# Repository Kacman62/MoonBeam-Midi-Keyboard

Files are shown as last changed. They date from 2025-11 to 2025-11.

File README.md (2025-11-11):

# MoonBeam Synthesizer
A standalone DAWLESS synthesizer based on a Raspberry Pi Pico. Includes a custom circuit board and codebase with the Mozzi Audio Library

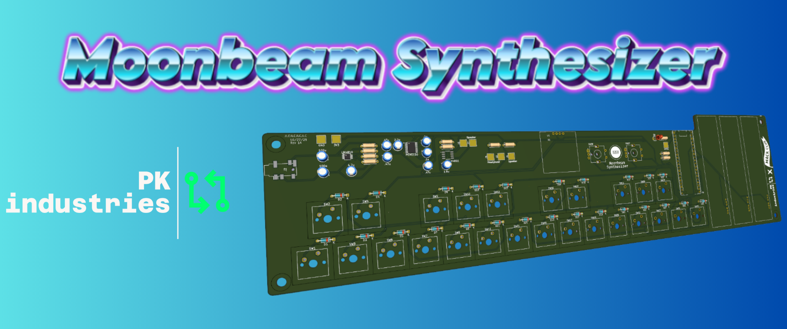
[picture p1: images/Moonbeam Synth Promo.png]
Promo Image for the Moonbeam Synth


# Features

- 25 multiplexed piano style keys
- Support for up to 5 notes at the same time
- 3 Analog sliders for volume pitch and vibrato
- OLED display and 2 rotary encoders with a custom code base
- Sound synthesis using the Mozzi audio library
- 4 different wave forms
- Custom ADSR editing
- Oscilloscope style waveform viewer
- Toggleable speaker and headphone out
- And more planned features for the future!

# Initial Idea
After reading the guide from Hack club and others online to make a MIDI keyboard, it seemed like a great idea. After more research though I wanted a standalone synthesizer that does not need a computer and couldn't find many examples online. This seemed like it would be easy enough so I decided to do it myself

# Schematic and Board
The whole project is built around a raspberry pi pico 1 (a pico 2 should work too but untested). A 5x5 multiplexed array of key cap switches serve as the main input. 
On the Audio side, a PCM5100 I2S DAC is channeled into a LM4810 and LM4861 audio amplifiers, that go to a speaker and headphone jack.

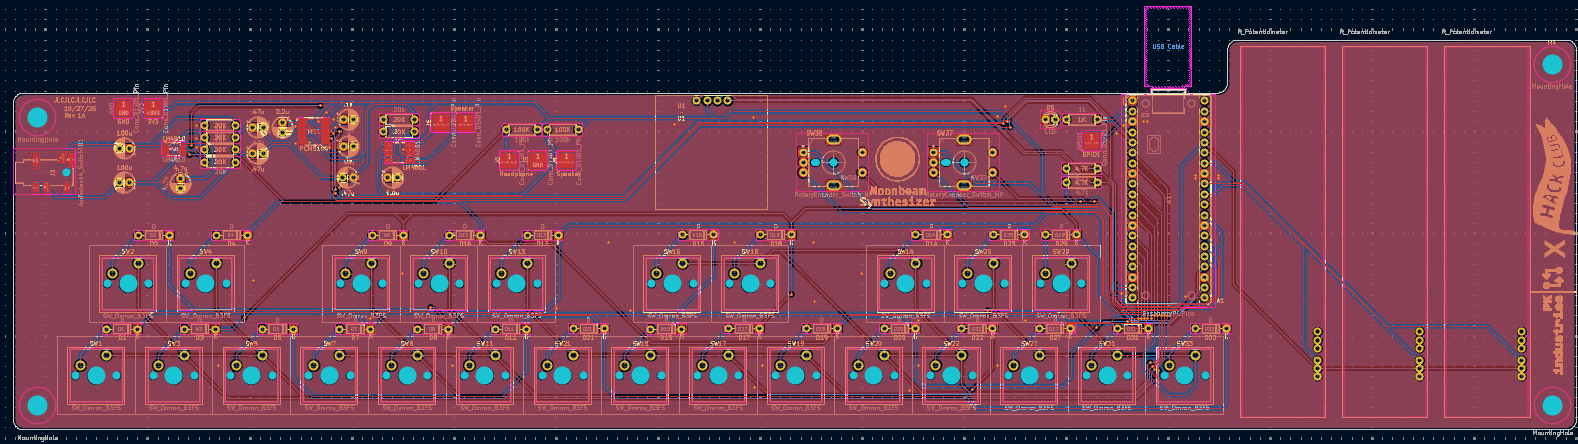
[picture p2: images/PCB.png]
Image showing routing of PCB


The PCB was a lot more challenging, just due to the sheer size of it. It ends up being about 350mm x 90mm. But the routing wasn't too hard and I like the look of how it turned out

# Case Design
There is an included case. Currently I have not received the board so I can not confirm if it works perfectly, but I designed it around the 3D cad of the board so it should work fine. 
Only 1 of each file needs to be printed and it is assembled using M4 hardware

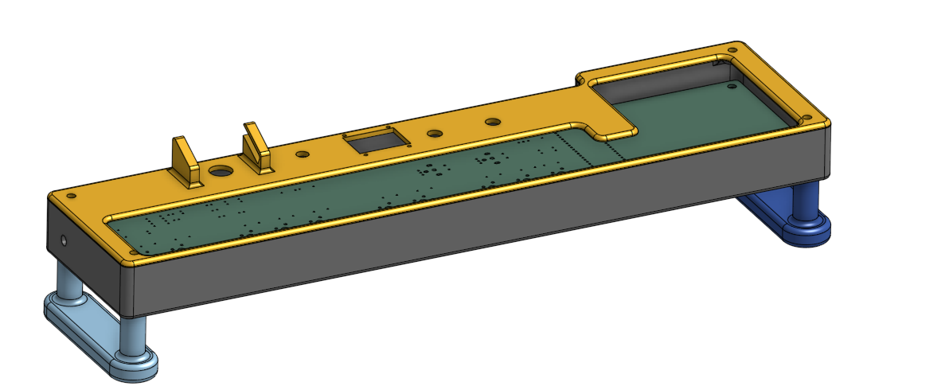
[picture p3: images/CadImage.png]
Image showing CAD of the case


# Software
I initially dreaded the software but it ended up being very fun after the initial hurdles. The code is split into 2 cores, 1 for audio and 1 for the digital UI. It should work with the final assembly, all the digital has been tested, but the audio is using I2S which I can't test currently. I did use it a little bit with PWM audio and that worked fine. The waveform viewer also does show an audio signal so Im pretty confident that it will work

# UI
You navigate the UI with both rotary encoders. Double clicking either brings you into the main menu. Rotate either to select an app.
* Settings (Wrench): View current notes on each audio voice and the values of the slide potentiometers
* ADSR Editor (Envelope): Use one dial to change the level of the ADSR and the other to change the time. Changing the level of the decay, sustain and release will change the other two with it. this is intended to avoid weird audio clipping
* Wave Viewer (Wave): View the current outputted wave form. Automatically adjusts the zoom if multiple voices are playing
* Wave Changer (Square Wave): Choose from either a sin, triangle, saw, or square wave

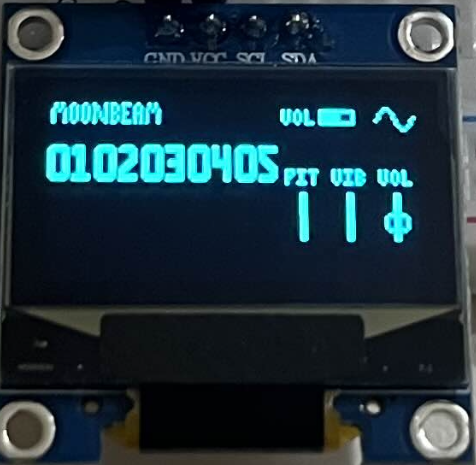
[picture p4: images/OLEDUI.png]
Image showing the settings UI


# Art
All pixel art was created by me using Aseprite. The PK Industries and the Moonbeam synth logo are unregistered trademarks, not real companies and products, and have no legal binding on anything. I am not a lawyer, and this joke has gone on too long.

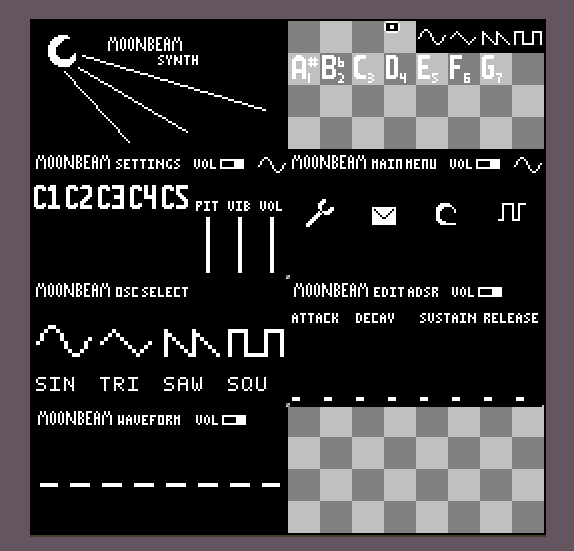
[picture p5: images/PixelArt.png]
Image showing the pixel art for the project


# Disclaimers
If you want to know more about the design and build process check out the journal

This project is sponsored by and made in collaboration with Hack Club, go check them out

Consider this project untested. I have put my full effort into this project and fully believe that it will work, but I have not received boards yet and thus do not know if this will work first try

# Hack Club Stuff

Estimate Total Hours: 48

My Final Total: 60.31

Your Final Total: 96.73

https://blueprint.hackclub.com/projects/928 

# Update 11/11

Huge thanks to Hack Club and the Blueprint program for assisting in this project. I have now received funding for the project and will be ordering parts. Expect future updates at the start of December

# Known issues
In settings, the note played is incorrect (going to wait for boards to arrive so I can assign keys different notes)

In Wave changer, the picture of the sawtooth wave is reversed from what is seen in the wave viewer

In Wave Viewer, the wave slides around randomly. (The wave is still representative of what the audio out looks like, it's just hard to focus on it)

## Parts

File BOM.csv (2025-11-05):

Product Name | Comapny | Product Link | Product Cost | Product Amount | Cost | Running Total | Do I have it? | My Total
Moonbeam Synth PCB | JLCPCB | https://github.com/Kacman62/MoonBeam-Midi-Keyboard/tree/main/PCBFiles | 32.9 | 1 | 32.9 | 32.9 | No | 32.9 | Includes Shipping
Pi Pico 1 | Vilros (really anywhere) | https://vilros.com/products/raspberry-pi-pico?src=raspberrypi | 4 | 1 | 4 | 36.9 | Yes | 32.9 | Pico 2 should work
Slider Potentiometers | Aliexpress | https://www.aliexpress.us/item/3256809748308736.html?curPageLogUid=286Us6b7kMqx | 1 | 3 | 3 | 39.9 | Yes | 32.9
Rotary Encoders | Aliexpress | https://www.aliexpress.us/item/3256808587124048.html?curPageLogUid=wcP5dpBKu0Kg | 5.72 | 1 | 5.72 | 45.62 | Yes | 32.9 | Comes in pack of 5, need 2
.96in OLED | Amazon | https://www.amazon.com/AITRIP-Display-Self-Luminous-Compatible-Raspberry/dp/B0F6SGQ9LZ | 11.99 | 1 | 11.99 | 57.61 | Yes | 32.9 | Comes in pack of 5, need 1. Careful that pinout is same, these are notorious for being unstandard
Keyswitches | Aliepress | https://www.aliexpress.us/item/3256808022543969.html?curPageLogUid=UsRw9gs5AusE | 6.05 | 1 | 6.05 | 63.66 | No | 38.95 | Buy 30 pack
Key Caps | Aliexpress | https://www.aliexpress.us/item/3256805328092200.html?gatewayAdapt=glo2usa4itemAdapt | 1.99 | 1 | 1.99 | 65.65 | No | 40.94 | Buy 30 pack
Speaker | Amazon | https://www.amazon.com/uxcell-Magnetic-Round-Shape-Replacement-Loudspeaker/dp/B08264X3KM | 5.49 | 1 | 5.49 | 71.14 | Yes | 40.94 | Pack of 2, need 1
Switch | Amazon | https://www.aliexpress.us/item/3256808627501124.html?curPageLogUid=D0IPUzBiYYWY | 2.84 | 1 | 2.84 | 73.98 | Yes | 40.94 | Pack of 5 need 1
Headphone Jack | LCSC | https://www.lcsc.com/product-detail/C128987.html?s_z=n_headphone | 0.19 | 5 | 0.95 | 74.93 | Yes | 40.94 | Min order 5, need 1
Various capacitors |  |  |  |  | 0 | 74.93 | Yes | 40.94 | might be slightly cheaper on lcsc, but just get a variety pack
Various Resistors |  |  |  |  | 0 | 74.93 | Yes | 40.94 | might be slightly cheaper on lcsc, but just get a variety pack
20k Resistors | LCSC | https://www.lcsc.com/product-detail/C119609.html?s_z=n_20k%2520resistor%2520tht | 0.046 | 10 | 0.46 | 75.39 | No | 41.4 | I need 20k resistors
THT LED |  |  |  |  | 0 | 75.39 | Yes | 41.4 | Optional for debugging
Diodes | LCSC | https://www.lcsc.com/product-detail/C402212.html?s_z=n_1n4148%2520diode | 0.009 | 50 | 0.45 | 75.84 | No | 41.85
PCM5100 I2S DAC | LCSC | https://www.lcsc.com/product-detail/C544856.html?s_z=n_pcm5100 | 1.06 | 1 | 1.06 | 76.9 | No | 42.91
LM4861 Speaker Amp | LCSC | https://www.lcsc.com/product-detail/C383073.html?s_z=n_lm4861 | 0.169 | 5 | 0.845 | 77.745 | No | 43.755 | Make sure to get an amp thats good for your speaker if you have one already. most are pin compatible
LM4810 Headphone Amp | LCSC | https://www.lcsc.com/product-detail/C2871753.html?s_z=n_lm4810 | 0.59 | 1 | 0.59 | 78.335 | No | 44.345
Various M4 Hardware
LCSC Shipping estimate and fees |  |  |  |  | 11.31
Aliexpress Shipping |  |  |  |  | 1.99 |  |  |  | If you buy more than i did you might get free shipping
With Taxes |  |  |  |  | 47.01
 |  |  |  |  |  | 96.73 |  | 60.31 | FINAL TOTAL

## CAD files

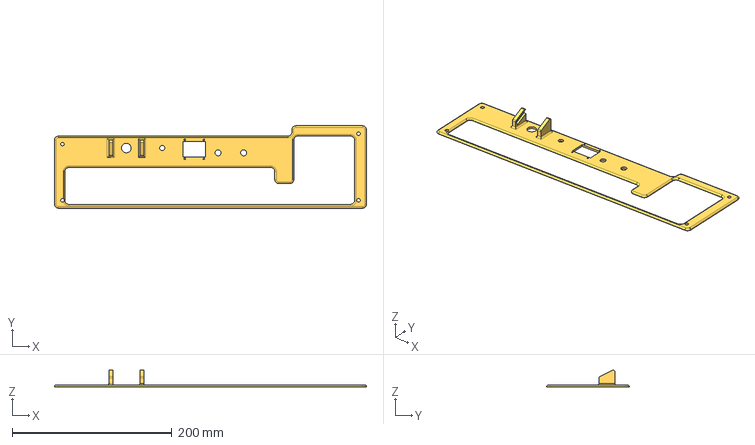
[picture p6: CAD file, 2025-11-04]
CadFolder/MoonBeam Midi Keyboard parts Copy 1 - Lid(3).step
391.0 x 103.5 x 21.3 mm

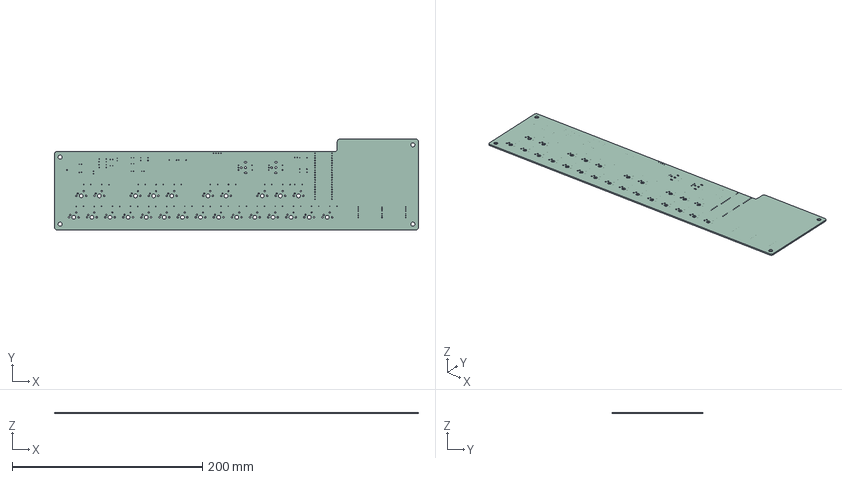
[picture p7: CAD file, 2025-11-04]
PCBFiles/Moonbeam Midi Keyboard parts Copy 1 - MoonBeam Midi Keyboard_PCB.step
383.0 x 95.5 x 1.51 mm

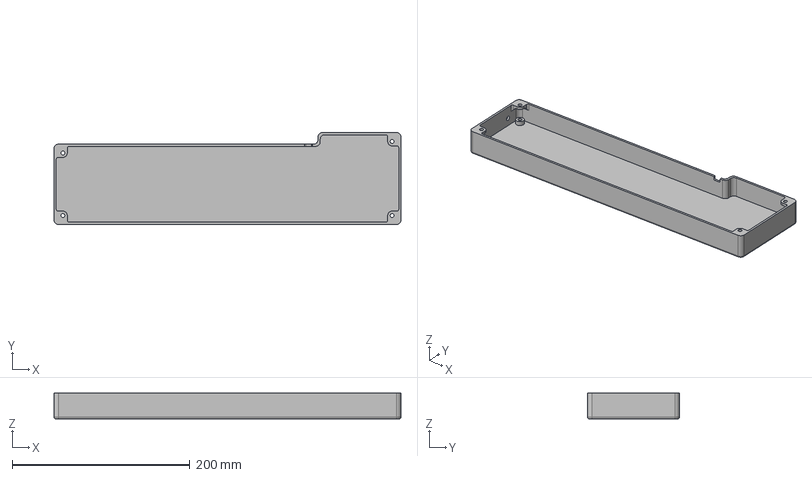
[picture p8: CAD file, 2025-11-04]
CadFolder/MoonBeam Midi Keyboard parts Copy 1 - Case.step
391.0 x 103.5 x 29.0 mm

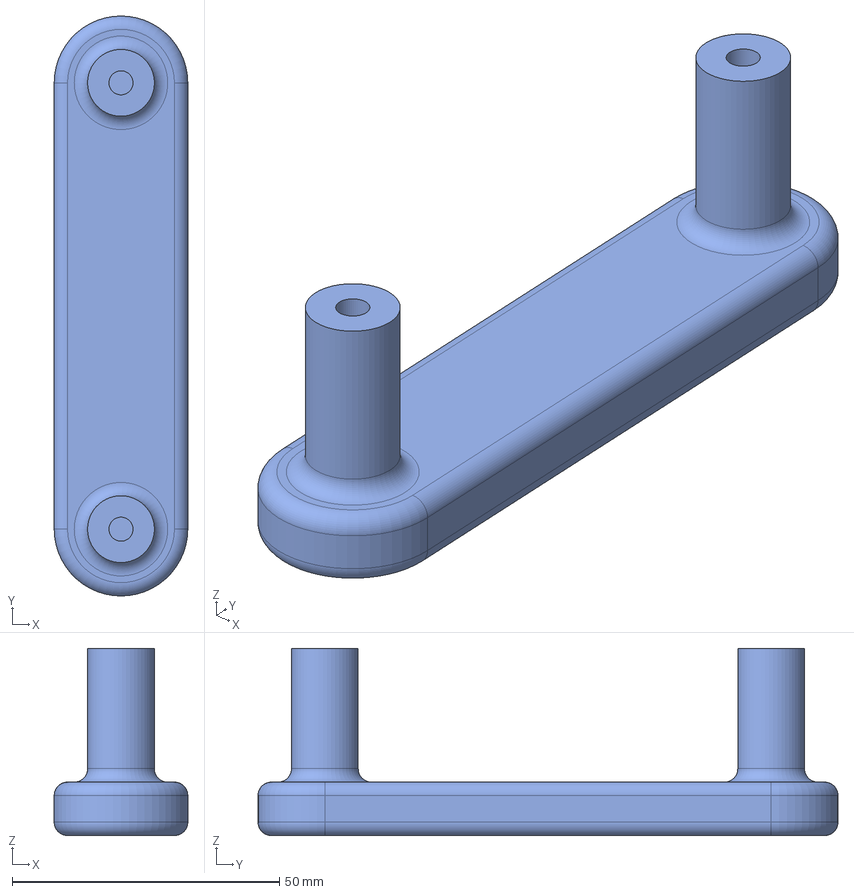
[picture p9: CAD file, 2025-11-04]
CadFolder/MoonBeam Midi Keyboard parts Copy 1 - Long Feet.step
25.0 x 108.5 x 35.0 mm

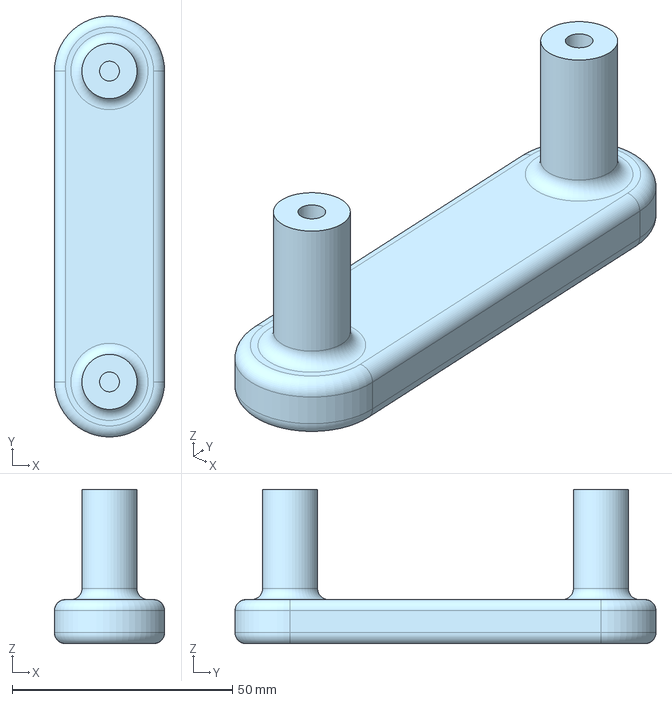
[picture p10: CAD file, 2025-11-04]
CadFolder/MoonBeam Midi Keyboard parts Copy 1 - Short Feet.step
25.0 x 95.5 x 35.0 mm

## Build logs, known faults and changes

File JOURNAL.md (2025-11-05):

<!--
  ===================    !!READ THIS NOTICE!!   ====================
  DO NOT edit this file manually. Your changes WILL BE OVERWRITTEN!
  This journal is auto generated and updated by Hack Club Blueprint.
  To edit this file, please edit your journal entries on Blueprint.
  ==================================================================
-->

## 10/25/2025 - First Prototype  



I spent most of this time in research. I liked the guide put out by hack club, but wanted a fully digital synthesizer, not just the controller. After looking at different chips and MCUs, I found that the mozzi library with a pi pico and an analog multiplexer and DAC would probably get me the best results. Before going into major PCB design, I wanted to make a breadboard cut down version just to prove it. I did get audio out of the speaker, and the next step is to get inputs and outputs from the pico.  

## 10/26/2025 1 PM - Finished Breadboard Prototype  



I spent most of this time upgrading the prototype. I added more buttons to 12, added another slide potentiometer, an I2C screen. 

I also started making code (with a lot of help from AI) it shows promise but I am having trouble getting the notes to sustain, so I might need to write the code myself.

Before that though, im going to design the PCB next and finalize the features. Going good so far though.  

## 10/26/2025 6 PM - Completed Schematic  




Spent a lot of this time researching how to get audio out. I took a headphone jack out of a broken usb adapter and wired it up in the schematic. I decided to use the pcm5100, and two TI chips, the lm4810 amd the 4861 to amplify the speaker and the headphones. Also did some other cleaning up, made a new footprint for the slide pots, added debug LEDS.

Next Im going to set out the PCB

## 10/27/2025 6 PM - Laid out and Routed PCB  





I laid out the PCB today. It was pretty challenging to get it all to fit together logically and in a small footprint. It ended up being about 350mm x 90mm. I'm pretty happy with how it looks and next I will work on making a cool silkscreen.

I also routed the PCB today, getting the multiplexed buttons was a little challenging, but I got it all done with a pretty small amount of vias. 

## 10/27/2025 9 PM - Added Silkscreen  




Went through all the components and added silkscreen of their values to make assembly easy. also added my and hack clubs logos. and found a moon pattern and added that to the back of the PCB. Also went to Logo.com and got a logo for the project made.

## 10/28/2025 - Cleaned Up Board and Started Code  



Mainly just cleaned up a bunch of loose ends this session. I cleaned up some routing things, replaced an LED with a GPIO test pad, adjusted the back silkscreen. I made a test print to see if the switch placement was good and it felt a little far away from front to back so I moved the back row closer to the front.

I also started (vibe) coding using the Mozzi audio library. the audio portion looks good, but i'm going to go back and try and make it myself.

Mainly just need to finish code and make a case before it is ready to be shipped.  

## 10/30/2025 - Started Case Design, Cleaned up Prototype Code  



Worked on the first version of the case. I like it, but it seems big so its going to be a real challenge to print and will need to be multiple pieces, so I will look into alternatives and optimizations.

Also cleaned up code for the prototype and started migrating it to the new design which uses a slightly different design than the prototype. 

I think im going to try multi core on the Pi Pico, but that will be my first time so I will see what happens.

## 11/1/2025 - Finished Case Design  



Finished the first revision of the case design. Had to go back and forth changing dimensions on the board and found that I put the wrong footprint on 1 screw hole. I think it looks pretty good but the lid doesn't seem super good so I might go back later. Looking like 200-250 grams for the entire thing which im pretty happy with.

Now its code time

## 11/2/2025 7 AM - More Coding  



Started by fixing some minor things in the CAD (forgot holes for the ports)
Then started adding in the OLED into the code. I got multicore on the pi pico, but for some reason the u8g2 graphics library didnt seem to work. (it could be multi core, or weird I2C pins, or a cheap knockoff OLED i dont really know). The adafruit ssd1306 and gfx libraries did work though. I also made a pixel art logo for the project.

Next steps are too modify parameters for the audio from the OLED.

## 11/2/2025 2 PM - Coded Main Menu  



Worked a lot on art and cleaning up code and some really weird bugs. I found out that the way i did multi core made core 0 freeze when core 1 started so i fixed that. I did more pixel art, creating graphics for what wave form is selected. Also added functions to change waveform and ADSR for later. biggest part though was creating the main menu screen where you can see the value of the sliders and in the future, what note is being played on each channel.

going really well so far i just really hope it works  

## 11/3/2025 - Added Menu Selection, Fixed Nasty Bug  



I added a rotary encoder and a menu selection screen as well as drawing icons for that. (last journal made this a little confusing this is the "main menu" that was like the main control page that shows what the synth is doing generally). I fixed a really weird bug with the encoders where the screen was drawing too many times and the delay in I2C writes was causing the encoders to not register rotations. (this issue was present across 2 different encoder libraries).

Ive got the wave form selector, the wave viewer, and the envelope editor left and then im done!  

## 11/4/2025 10 AM - Added ADSR Editing and Waveform Switching  



I added two more menus today with "art" for both. You can now switch wave forms to either sin, triangle, saw, or square. The icon in the banner also changes accordingly. 

I also added a way to change the ADSR curve of the waveform. you use one rotary encoder to change time and the other to change the level. 

Going to add 1 last app to view the current outputted wave, like an Oscope and then im going to be done with software for now.

## 11/4/2025 4 PM - Finished Code with Waveform Viewer  



I think im finished with the code. I added a waveform viewer for the audio out. It works with different wave types and (should) change with the pitch and vibrato sliders. 

This code has been a beast but im going to upload it to the github have some people review it and then ship on the weekend.

## 11/4/2025 7 PM - Shipped  

Moonbeam Synth Promo

Made a promo image for the project. Created a BOM. updated the Github a lot. uploaded code, cad, PCB files. Also shipped the project and waiting for review. 
So happy with how this turned out and cant wait to get it and continue making improvements on it.

## 11/5/2025 - Shaved $30 Off BOM  

I got over my fear of Aliexpress and got the total cost for me and you down by $30. Amazon shipping was pretty expensice. Now im ready to ship and start ordering pieces. 



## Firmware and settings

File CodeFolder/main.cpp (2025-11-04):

#include "Wire.h"
#include "pico/multicore.h"
#include "core_shared.h"

///////
#include <MozziConfigValues.h>// include this first, for named option values

#define MOZZI_AUDIO_MODE MOZZI_OUTPUT_I2S_DAC

#define MOZZI_AUDIO_CHANNELS MOZZI_STEREO           // set to stereo mode

#define MOZZI_AUDIO_BITS    16  // available values are 8, 16 (default), 24 (LEFT ALIGN in 32 bits type!!) and 32 bits
#define MOZZI_I2S_PIN_BCK                        2 // /BLCK) default is 20
#define MOZZI_I2S_PIN_WS (MOZZI_I2S_PIN_BCK+1)  // CANNOT BE CHANGED, HAS TO BE NEXT TO pBCLK, i.e. default is 21
#define MOZZI_I2S_PIN_DATA                       18 // (DOUT) default is 22
#define MOZZI_I2S_FORMAT MOZZI_I2S_FORMAT_PLAIN

#define AUDIO_RATE 16384
#define MOZZI_CONTROL_RATE 128

#include <Mozzi.h>                                  // *after* all configuration options, include the main Mozzi headers

#include <Oscil.h>
#include <ADSR.h>

#include <tables/sin2048_int8.h>
#include <tables/saw2048_int8.h>  
#include <tables/square_no_alias_2048_int8.h> 
#include <tables/triangle2048_int8.h>



#define VOL_POT   A0   // GP26
#define PITCH_POT A1   // GP27
#define VIB_POT   A2   // GP28

volatile float masterVol = 1.0f;
volatile float pitchOffset = 0.0f;
volatile float vibDepth = 0.0f;

#define NUM_COLS 5
#define NUM_ROWS 5

Oscil<SIN2048_NUM_CELLS, AUDIO_RATE> osc[NUM_VOICES] = {
  Oscil<SIN2048_NUM_CELLS, AUDIO_RATE>(SIN2048_DATA),
  Oscil<SIN2048_NUM_CELLS, AUDIO_RATE>(SIN2048_DATA),
  Oscil<SIN2048_NUM_CELLS, AUDIO_RATE>(SIN2048_DATA),
  Oscil<SIN2048_NUM_CELLS, AUDIO_RATE>(SIN2048_DATA),
  Oscil<SIN2048_NUM_CELLS, AUDIO_RATE>(SIN2048_DATA)
};

ADSR<CONTROL_RATE, AUDIO_RATE> env[NUM_VOICES];

volatile SharedADSR adsrSettings;

volatile bool ADSR_FLAG = false;
volatile bool OSC_FLAG = false;

volatile OSCState wave = SIN;

extern const unsigned char sinWave[];
extern const unsigned char triWave[];
extern const unsigned char sawWave[];
extern const unsigned char squareWave[];
extern const unsigned char* waveTable[];

Oscil<SIN2048_NUM_CELLS, AUDIO_RATE> lfo(SIN2048_DATA);  // LFO for vibrato

int voiceNoteIndex[NUM_VOICES] = {-1, -1, -1, -1, -1};

volatile float notePlayArray[NUM_VOICES] = {-1, -1, -1, -1, -1};

int voicesPlaying = 0;

int ButtonMatrixRow[NUM_ROWS] = {4, 5, 6, 7, 8};
int ButtonMatrixCol[NUM_COLS] = {9, 10, 11, 12, 13};

float noteFreqs[NUM_ROWS * NUM_COLS] = {
  261.63, 277.18, 293.66, 311.13, 329.63,
  349.23, 369.99, 392.00, 415.30, 440.00,
  466.16, 493.88, 523.25, 554.37, 587.33,
  622.25, 659.25, 698.46, 739.99, 783.99,
  830.61, 880.00, 932.33, 987.77, 1046.5
}; //C4-C6

void scanMatrix();
void triggerVoice(int);
void releaseVoice(int);
void core1_entry();
void updateADSR();
void updateOSC();

void setup(){


  //Blink LED so i know its working (ONLY FOR DEBUGGING)
  pinMode(0, OUTPUT);
  digitalWrite(0, HIGH);
  delay(500);
  digitalWrite(0, LOW);
  delay(200);


   for (int r = 0; r < NUM_ROWS; r++) {
    pinMode(ButtonMatrixRow[r], OUTPUT);
    digitalWrite(ButtonMatrixRow[r], LOW);
  }
  for (int c = 0; c < NUM_COLS; c++) {
    pinMode(ButtonMatrixCol[c], INPUT_PULLDOWN);
  }

  updateADSR();
  updateOSC();

  lfo.setFreq(5.0f);

  digitalWrite(0, HIGH);
  delay(500);
  digitalWrite(0, LOW);
  delay(20);
  digitalWrite(0, HIGH);
  delay(500);
  digitalWrite(0, LOW);
  delay(200);

  analogReadResolution(12); // 0–4095
  
  startMozzi();

}

const int WAVEFORM_SAMPLES = 128;
volatile int16_t waveformBuffer[WAVEFORM_SAMPLES];
volatile int waveformIndex = 0;

AudioOutput updateAudio() {
  int32_t mix = 0;
  for (int i = 0; i < voicesPlaying; i++) {
    int16_t envVal = env[i].next();
    int16_t oscVal = osc[i].next();
    mix += (oscVal * envVal) >> 8; 
  }

  if(voicesPlaying == 0){
    return StereoOutput::from16Bit(0, 0);
  }

  mix = (mix * masterVol) / voicesPlaying; // normalize and apply volume

  // constrain mix to 16 bit range
  mix = constrain(mix, -32767, 32767);

  waveformBuffer[waveformIndex] = mix; // hope this doesnt cause to much overhead. may need to move to update control loop
  waveformIndex = (waveformIndex + 1) % WAVEFORM_SAMPLES;

  return StereoOutput::from16Bit((int16_t)mix, (int16_t)mix);
}



void loop(){
  audioHook();
}



void updateControl(){

  masterVol = analogRead(VOL_POT) / 4095.0;
  pitchOffset = analogRead(PITCH_POT) / 4095.0;
  vibDepth = analogRead(VIB_POT) / 4095.0;

  float freq_shift = vibDepth * ((float)lfo.next() / 128.0f);

  for (int i = 0; i < NUM_VOICES; i++) {
  if (env[i].playing() && voiceNoteIndex[i] != -1) {
    float baseFreq = noteFreqs[voiceNoteIndex[i]];
    osc[i].setFreq(baseFreq * (1.0f + pitchOffset + freq_shift));
  }
}

if(ADSR_FLAG){
  updateADSR();
}

if(OSC_FLAG){
  updateOSC();
}

  scanMatrix();

}

bool wasPressed[NUM_ROWS * NUM_COLS] = {false};

void scanMatrix() {
  for (int r = 0; r < NUM_ROWS; r++) {
    digitalWrite(ButtonMatrixRow[r], HIGH); // enable row

    for (int c = 0; c < NUM_COLS; c++) {
      int idx = r * NUM_COLS + c;
      bool pressed = digitalRead(ButtonMatrixCol[c]) == HIGH;

      if (pressed && !wasPressed[idx]) { // note on
        wasPressed[idx] = true;
        triggerVoice(idx);
      } else if (!pressed && wasPressed[idx]) { // note off
        wasPressed[idx] = false;
        releaseVoice(idx);
      }
    }

    digitalWrite(ButtonMatrixRow[r], LOW); // disable row
  }
}


void triggerVoice(int noteIdx) {
  for (int i = 0; i < NUM_VOICES; i++) {
    if (!env[i].playing()) { 
      float freq = noteFreqs[noteIdx] * (1.0f + pitchOffset);
      osc[i].setFreq(freq); 

      notePlayArray[i] = freq;

      env[i].noteOn();
      voiceNoteIndex[i] = noteIdx;
      break;
    }
  }

  voicesPlaying++;
}


void releaseVoice(int noteIdx) {
  for (int i = 0; i < NUM_VOICES; i++) {
    // Check if this voice is currently playing the note that was just released
    // This ensures the correct voice's envelope is sent to the release stage.
    if (voiceNoteIndex[i] == noteIdx) {
      env[i].noteOff();
      voiceNoteIndex[i] = -1; // Mark voice as free

      notePlayArray[i] = -1;
      
      break; // Found and released the note, stop searching
    }
  }
  voicesPlaying--;
}

void updateADSR(){
  for (int i = 0; i < NUM_VOICES; i++){
    env[i].setLevels(adsrSettings.attack, adsrSettings.decay, adsrSettings.sustain, adsrSettings.release);
    env[i].setTimes(adsrSettings.attackTime, adsrSettings.decayTime, adsrSettings.sustainTime, adsrSettings.releaseTime);
  }
  ADSR_FLAG = false;
}



void updateOSC(){
  for (int i = 0; i < NUM_VOICES; i++){
    
    switch(wave){

      case SIN: 
        osc[i].setTable(SIN2048_DATA); 
        break;

      case TRIANGLE: 
        osc[i].setTable(TRIANGLE2048_DATA); 
        break;

      case SAW: 
        osc[i].setTable(SAW2048_DATA); 
        break;

      case SQUARE: 
        osc[i].setTable(SQUARE_NO_ALIAS_2048_DATA); 
        break;
    }
  }
   OSC_FLAG = false;
}

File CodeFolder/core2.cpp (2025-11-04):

//*********** CORE 2 AREA **************/
#include <Adafruit_SSD1306.h>
#include <Adafruit_gfx.h>
#include <EEncoder.h>
#include <Button2.h>
#include <cmath>

#include "core_shared.h"
#include "images.h"

#define SDA 16
#define SCL 17

#define SCREEN_WIDTH 128 // OLED display width, in pixels
#define SCREEN_HEIGHT 64 // OLED display height, in pixels

#define OLED_RESET     -1 
#define SCREEN_ADDRESS 0x3C 

Adafruit_SSD1306 display(SCREEN_WIDTH, SCREEN_HEIGHT, &Wire, OLED_RESET);

int RotaryButton1 = 15;
EEncoder encoder1(19, 20); 
Button2 button1(RotaryButton1); 

int RotaryButton2 = 14;
EEncoder encoder2(21, 22); 
Button2 button2(RotaryButton2); 

long lastPos1;
long lastPos2;

void onButtonClick1(Button2 &btn);
void onButtonClick2(Button2 &btn);
void onButtonDoubleClick1(Button2 &btn);
void onButtonDoubleClick2(Button2 &btn);
void animationIntro();
void openCloseAnimation(bool open, const unsigned char* bitMapOut);
void updateScreen();

void showSettings();
void showMain();
void showOscSettings();
void showADSR();
void showWaveForm();

void onEncoderRotate(EEncoder& enc);

extern const unsigned char PKI_Logo_BW [];
extern const unsigned char MoonBeamSynth [];
extern const unsigned char slider[];
extern const unsigned char menuHeader[];

extern const unsigned char settingsMenu[];
extern const unsigned char mainMenu[];
extern const unsigned char OSCMenu [];
extern const unsigned char ADSRMenu [];
extern const unsigned char waveFormMenu [];

extern const unsigned char* menuItems[];
extern const int menuItemsNum;

extern const unsigned char* notes[];
extern const unsigned char* numbers[];
extern const unsigned char sharp[];
extern const unsigned char flat[];

extern volatile float masterVol;
extern volatile float pitchOffset;
extern volatile float vibDepth;

extern volatile bool OSC_FLAG;
extern volatile bool ADSR_FLAG;

extern const unsigned char* waveTable[];

extern volatile float notePlayArray[];

enum menuState {
  MAIN_MENU, //Sekect other menus here 
  SETTINGS, //Show current pot values and other settings (maybe also what note is playing)
  ADSR_SETTINGS, //Tweak the envolope show a waveform of what it looks like
  WAVEFORM, //Show waveform of current played note
  OSC_SETTINGS, //Change osc shape and frequency 
  PRESETS, //preset ADSR etc
  LOOPER, // looper or sequencer probably do this last
  CHORDS // play chords with single button and change major minor etc.
};

menuState Menu = MAIN_MENU;

extern volatile SharedADSR adsrSettings;

int mainMenuItem  = 0;

int oscSettingSelected = 0;
int oscSettingMax = 4;

int adsrSettingSelected = 0;
int adsrSettingMax = 4;

void setup1(){

   Serial.begin(115200);

  //Blink LED so i know its working (ONLY FOR DEBUGGING)
  pinMode(25, OUTPUT);
  digitalWrite(25, HIGH);
  delay(500);
  digitalWrite(25, LOW);
 
  Wire.setSDA(SDA);
  Wire.setSCL(SCL);
  Wire.begin();

  delay(50);


  Serial.println("Init OLED...");
  display.begin(SSD1306_SWITCHCAPVCC, SCREEN_ADDRESS);
  display.display();
  Serial.println("OLED init done");

  display.clearDisplay();

  display.drawBitmap(0, 0, PKI_Logo_BW, 127, 64, 1);
  display.display();

  button1.begin(RotaryButton1, INPUT_PULLUP, true);
  button1.setClickHandler(onButtonClick1);
  button1.setDoubleClickHandler(onButtonDoubleClick1);

  button2.begin(RotaryButton2, INPUT_PULLUP, true);
  button2.setClickHandler(onButtonClick2);
  button2.setDoubleClickHandler(onButtonDoubleClick2);

  encoder1.setEncoderHandler(onEncoderRotate);
  encoder2.setEncoderHandler(onEncoderRotate);

  encoder1.setAcceleration(false);
  //encoder1.setAccelerationRate(5);
  encoder2.setAcceleration(false);
  //encoder2.setAccelerationRate(5);

  delay(1000);

  display.clearDisplay();

  display.drawBitmap(0, 0, MoonBeamSynth, 127, 64, 1);
  display.display();

  delay(1500);

  display.clearDisplay();
}

void onButtonClick1(Button2 &btn){

  if(Menu == MAIN_MENU){
    Menu = static_cast<menuState>(mainMenuItem + 1); //+1 because 0th item is main menu

    if(mainMenuItem == 1) {
      adsrSettingSelected--; // maybe shoulda debounced it or smth
      encoder1.setAcceleration(true);
      encoder1.setAccelerationRate(5);
    }

  }

  if(Menu == OSC_SETTINGS){
    wave = static_cast<OSCState>(oscSettingSelected);
    OSC_FLAG = true;
  }

  if(Menu == ADSR_SETTINGS){
    adsrSettingSelected++;

    // Wrap around
    if (adsrSettingSelected < 0) 
      adsrSettingSelected = adsrSettingMax - 1;
    if (adsrSettingSelected >= adsrSettingMax) 
      adsrSettingSelected = 0;

    Serial.print("adsr Setting Item: ");
    Serial.println(adsrSettingSelected);
  }

}

void onButtonClick2(Button2 &btn){
  
  if(Menu == MAIN_MENU){
    Menu = static_cast<menuState>(static_cast<int>(Menu) + mainMenuItem + 1); 

    if(mainMenuItem == 1){
      adsrSettingSelected--;
      encoder1.setAcceleration(true);
      encoder1.setAccelerationRate(5);
    }
  }

  if(Menu == OSC_SETTINGS){
    OSC_FLAG = true;
    wave = static_cast<OSCState>(static_cast<int>(wave) + oscSettingSelected);
  }

  if(Menu == ADSR_SETTINGS){
    adsrSettingSelected++;

    // Wrap around
    if (adsrSettingSelected < 0) 
      adsrSettingSelected = adsrSettingMax - 1;
    if (adsrSettingSelected >= adsrSettingMax) 
      adsrSettingSelected = 0;

    Serial.print("adsr Setting Item: ");
    Serial.println(adsrSettingSelected);
  }

}

void onButtonDoubleClick1(Button2 &btn){

  if(Menu == ADSR_SETTINGS){
    ADSR_FLAG = true;
    encoder1.setAcceleration(false);
    encoder2.setAcceleration(false);
  }

  Menu = MAIN_MENU;
  
}

void onButtonDoubleClick2(Button2 &btn){

  if(Menu == ADSR_SETTINGS){
    ADSR_FLAG = true;
    encoder1.setAcceleration(false);
    encoder2.setAcceleration(false);
  }
  
  Menu = MAIN_MENU;
}

long lastRefresh = millis();

void loop1(){

  if(millis() - lastRefresh > 50){ // yeah this fixes issue below. theres 2 hours ill never get back
  
  updateScreen(); // i think calling this to much is messing with the encoders
  lastRefresh = millis();

  }

  encoder1.update();
  encoder2.update();

  button1.loop();
  button2.loop();

}

void updateScreen(){

  display.clearDisplay();

  switch(Menu){

    case SETTINGS: 
      showSettings();
    break;

    case MAIN_MENU: 
      showMain();
    break;

    case OSC_SETTINGS:
      showOscSettings();
    break;

    case ADSR_SETTINGS:
      showADSR();
    break;

    case WAVEFORM:
      showWaveForm();
    break;

  }

  
  display.drawBitmap(0, 0, menuHeader, 128, 16, 1); //header

  display.fillRect(95, 6, 10, 3, 0); //volume on header
  display.fillRect(95, 6, (int) 10 * masterVol, 3, 1);

  display.drawBitmap(112, 0, waveTable[static_cast<int>(wave)], 16, 16, 1); // fun hack to draw wave type

  display.display();

}

void showSettings(){

display.drawBitmap(0, 0, settingsMenu, 128, 64, 1);
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

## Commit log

2025-11-04 Add MoonBeam Midi Keyboard PCB file
    [Moonbeam Midi Keyboard parts Copy 1 - MoonBeam Midi Keyboard_PCB.step]
2025-11-04 Rename MoonBeam Midi Keyboard.kicad_pcb to MoonBeam Midi Keyboard.kicad_pcb
    [MoonBeam Midi Keyboard.kicad_pcb]
2025-11-04 Fix file path typo in PCBFiles directory
2025-11-04 Rename MoonBeam Midi Keyboard.kicad_pro to MoonBeam Midi Keyboard.kicad_pro
2025-11-04 Update and rename MoonBeam Midi Keyboard.kicad_sch to MoonBeam Midi Keyboard.kicad_sch
    [MoonBeam Midi Keyboard.kicad_sch]
2025-11-05 Rename Screenshot 2025-11-04 181659.png to PCB .png
2025-11-05 Rename PCB .png to PCB.png
2025-11-05 Add PCB routing image to README
    Added an image to the README for PCB routing visualization.
2025-11-05 Change PCB image in README
    Updated PCB image link in README.md.
2025-11-05 Include CAD image in README
    Added an image of the CAD design for the case.
2025-11-05 Update and rename Moonbeam Synth CSV - Sheet1.csv to BOM.csv
    [BOM.csv]
2025-11-05 Update and rename Moonbeam Synth CSV - Sheet1(1).csv to BOM.csv
    [BOM.csv]
2025-11-05 Update and rename Moonbeam Synth CSV - Sheet1(2).csv to BOM.csv
    [BOM.csv]
